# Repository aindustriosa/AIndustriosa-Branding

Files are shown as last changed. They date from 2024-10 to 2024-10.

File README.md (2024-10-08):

# AIndustriosa-Branding
Panel de logos de patrocinadores e colaboradores interactivo, construidos mediante ferramentas de fabricación dixital (Impresión 3D, corte laser, CNC…)

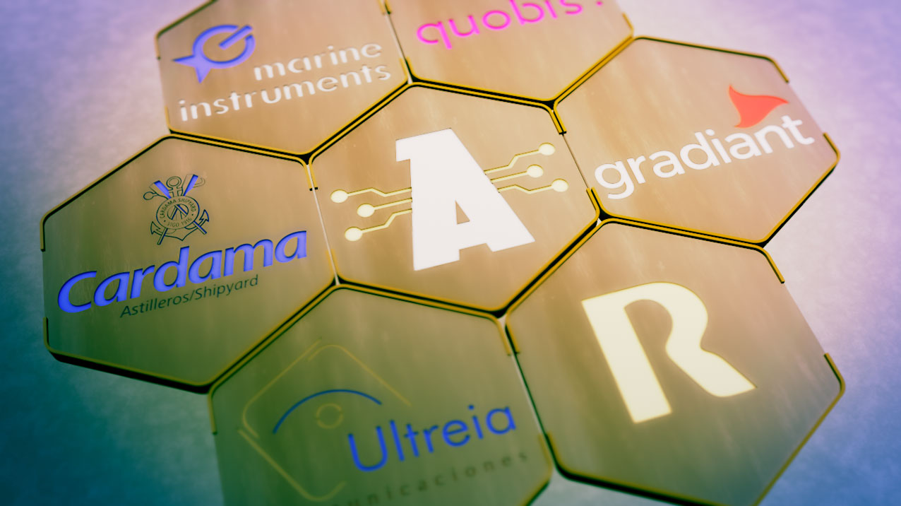
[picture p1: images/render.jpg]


Durante este ano un dos proxectos propostos foi a elaboración dun novo panel de patrocinadores, intentando empregar todos os medios disponibles na Industriosa.

A idea era facer un panel interactivo de logos que se poidese integrar co Home Assistant do local, e usalo tamben de sinalítica.

A parte electrónica usamos tiras de led RGB de 5V coa idea que mediante sinxelas circuitos con un microcontrolador controlar cada panel.

Para empezar o deseño da base foi elaborada con InkScape.

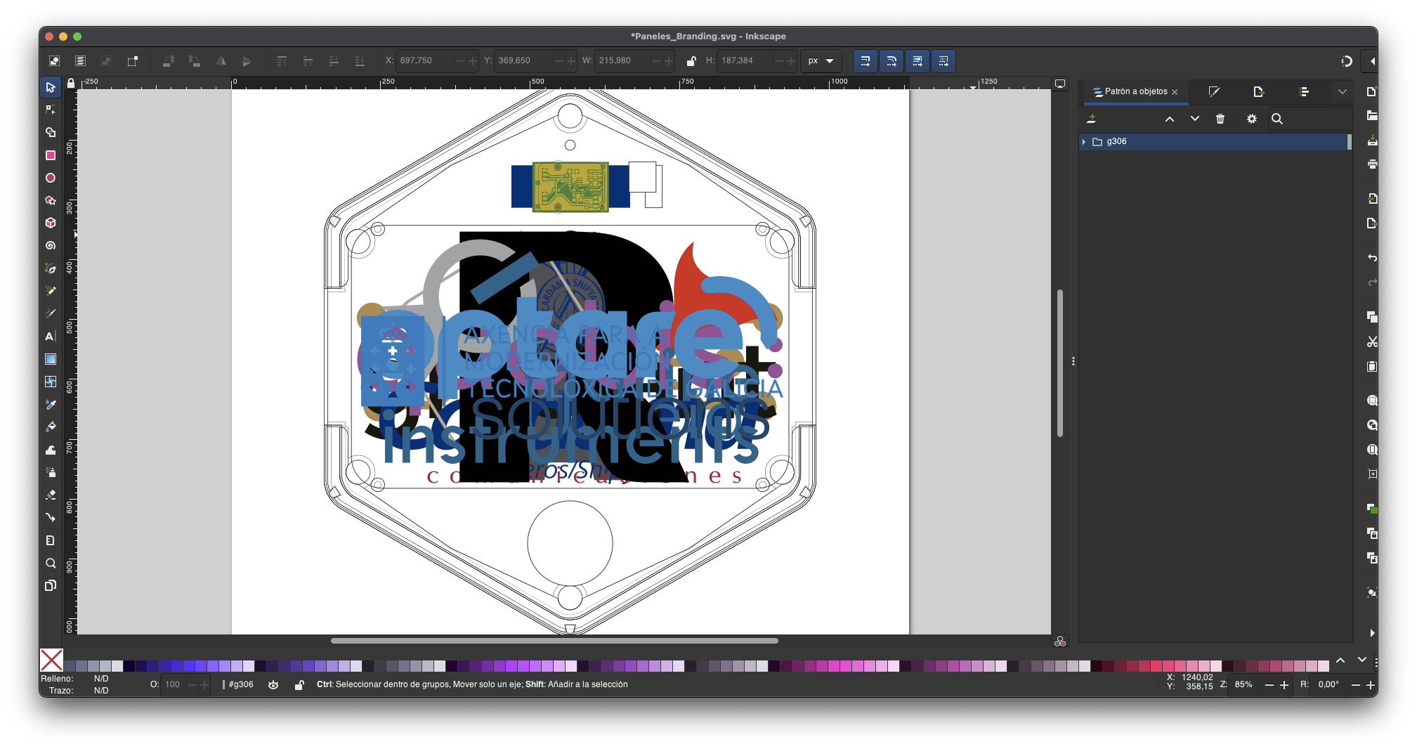
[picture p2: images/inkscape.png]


Partindo los vectores modelamos nun programa de 3d mediante ferramentas de extrusión e operacións boleanas as bases e soportes los leds.

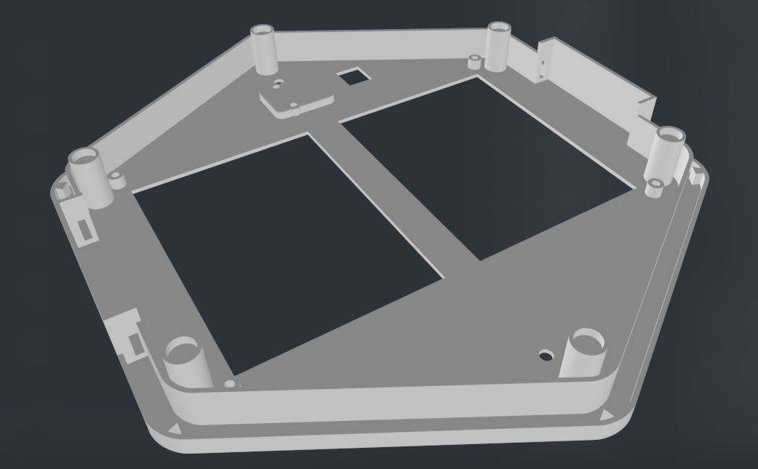
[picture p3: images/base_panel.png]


Con mesmo SVG sacamos os soportes dos leds de cada logo, deixando unha marxe para colocar as luces.

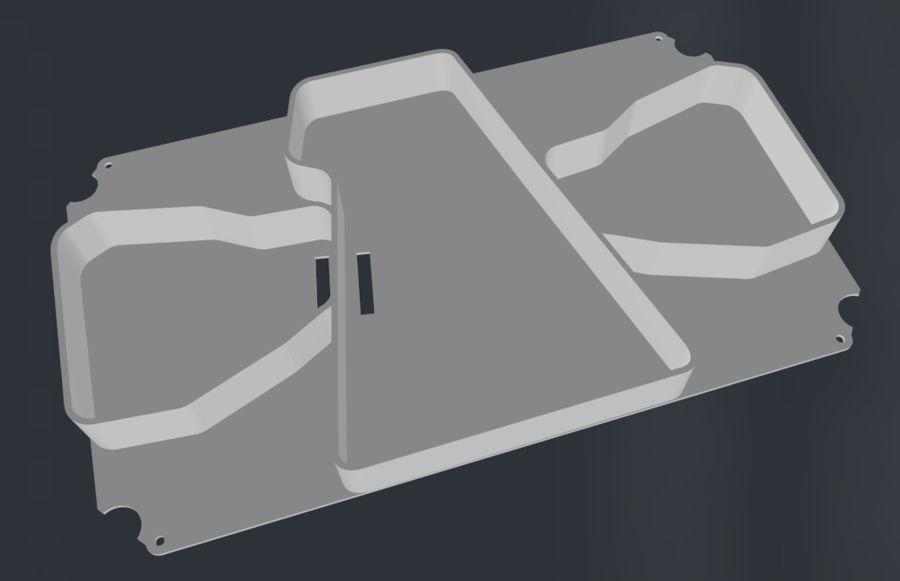
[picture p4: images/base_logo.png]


A maioria dos elementos foron impresos en 3d, dende as bases con PLA negro e as partes translucidas en PLA blanco con apenas 2 capas de recheo.

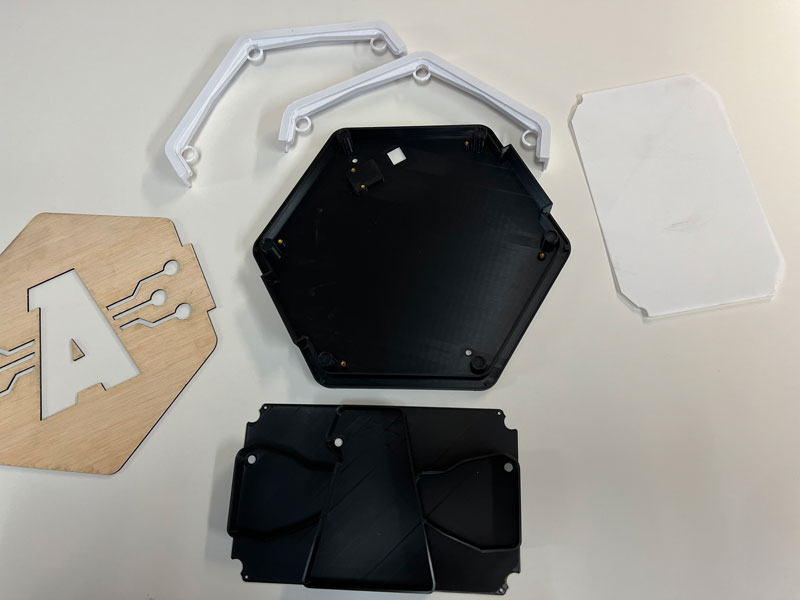
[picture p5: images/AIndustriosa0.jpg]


Para o deseño das pcbs, usamos o kicad, facendo unha sinxela placa cun Atiny412, dos saidas para duas tiras leds, toma de corrente e I2C, así como pin para programalos por UPDI

# Lista de materiais BOM

- Placas de Circuito de PCB **FR1** [Amazon](https://www.amazon.es/dp/B087M1GDCP?psc=1&smid=A839N7HCQOMKL&ref_=chk_typ_imgToDp)
- Fresa 0.4 End Mill -> 1/32 -> 0,4 MM -> TRACES [Aliexpress](https://es.aliexpress.com/item/32914096470.html?spm=a2g0o.order_list.0.0.19bb194dGODsyC&gatewayAdapt=glo2esp)
- Fresa 0.8 End Mill -> 1/64 -> 0,8 MM -> CUT [Aliexpress](https://es.aliexpress.com/item/32914096470.html?spm=a2g0o.order_list.0.0.19bb194dGODsyC&gatewayAdapt=glo2esp)

| Compoñente | Unidades | Código | Tenda | Footprint |
| ----- | ---- | ---- | ---- | ---- |
| ATtiny412 | 1 | ATTINY412-SSF-ND | [Digikey](https://www.digikey.es/en/products/detail/microchip-technology/ATTINY412-SSF/9947539) | SOIC-8_3.9x4.9mm_P1.27mm |
| Cap 10 uF | 1 | GRT31CC8YA106ME01L | [Digikey](https://www.digikey.es/en/products/detail/murata-electronics/GRT31CC8YA106ME01L/5416847) | C_1206 |
| Res 0 Ohms | 1 | RC1206FR-070RL | [Digikey](https://www.digikey.com/en/products/detail/yageo/RC1206FR-070RL/5698945) | R_1206 |
| Res 499 Ohms | 1 | RC1206FR-07499RL | [Digikey](https://www.digikey.es/en/products/detail/yageo/RC1206FR-07499RL/728944) | R_1206 |
| LED RED | 1 | 1516-1076-1-ND  | [Digikey](https://www.digikey.es/es/products/detail/qt-brightek-qtb/QBLP615-R/4814674) | LED_1206 |
| Connector 1x03_P2.54mm_Horizontal | 3 | S1143E-36-ND  | [Digikey](https://www.digikey.es/es/products/detail/sullins-connector-solutions/GBC36SGSN-M89/862355) | PinHeader_1x03_P2.54mm_Horizontal_SMD |
| Connector 2x10_P2.54mm_Vertical | 3 | 20021121-00010T1LF  | [Digikey](https://www.digikey.es/en/products/detail/amphenol-icc-fci/20021121-00010T1LF/4243614) | PinHeader_1x03_P2.54mm_Horizontal_SMD |

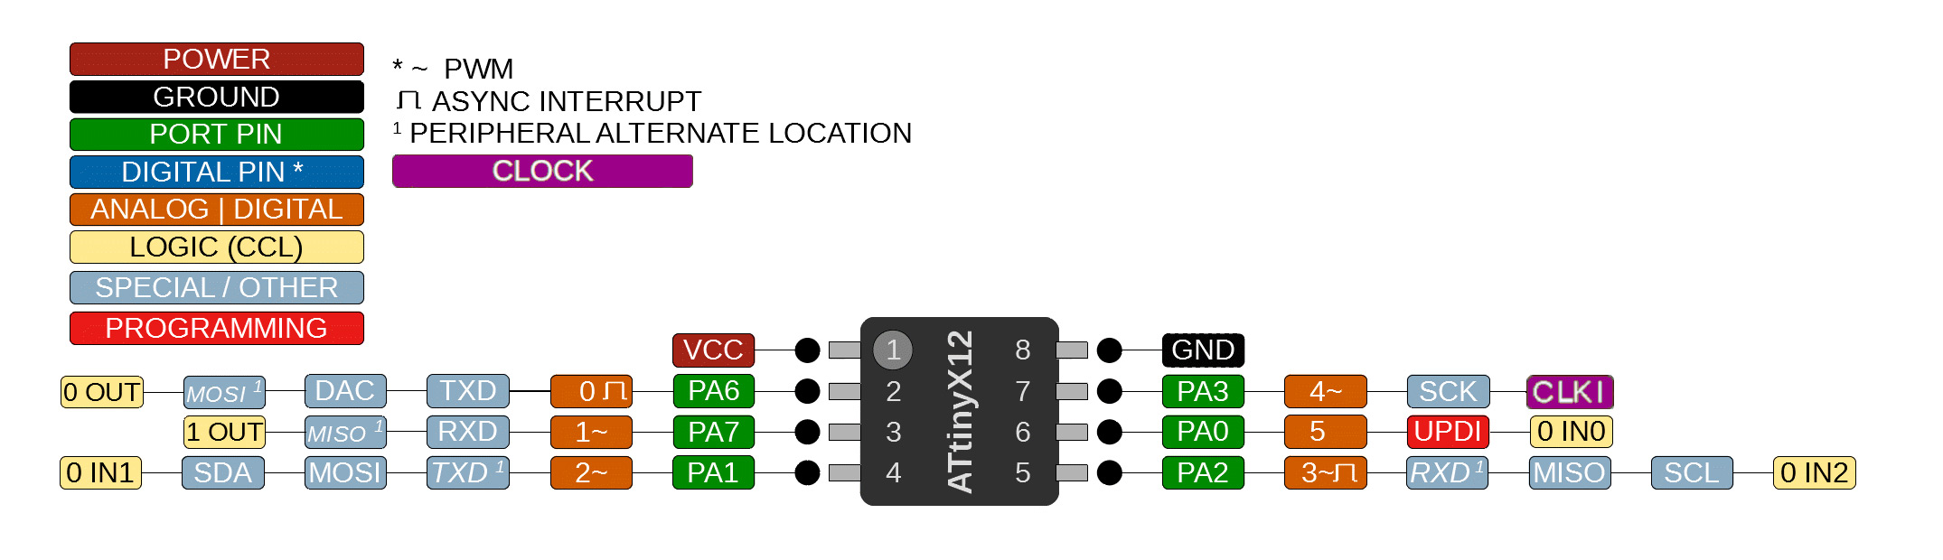
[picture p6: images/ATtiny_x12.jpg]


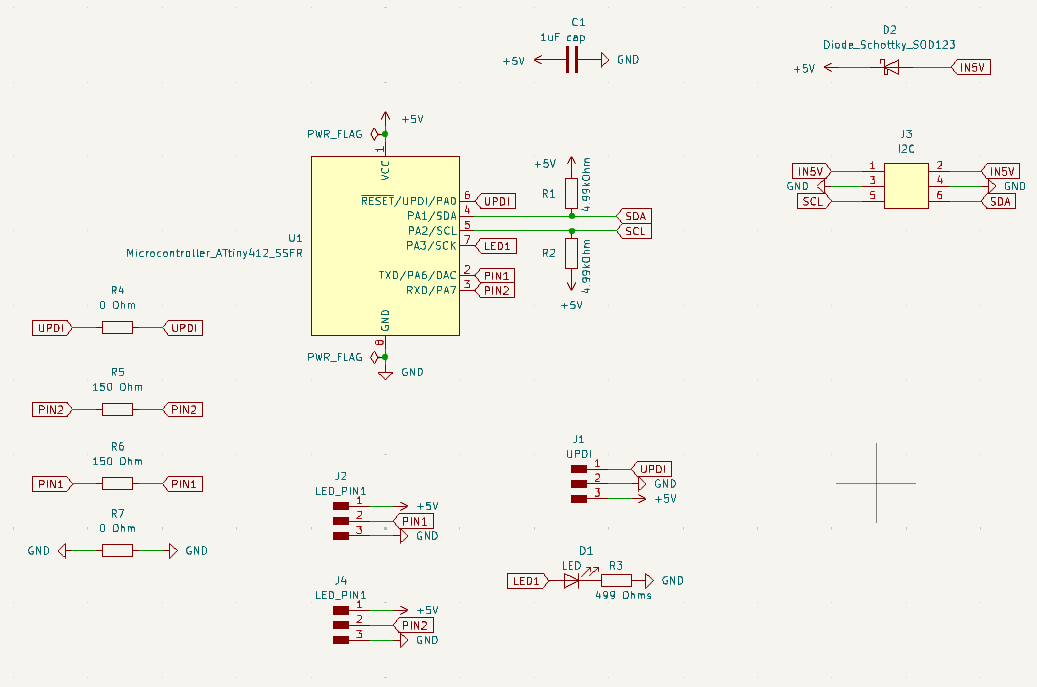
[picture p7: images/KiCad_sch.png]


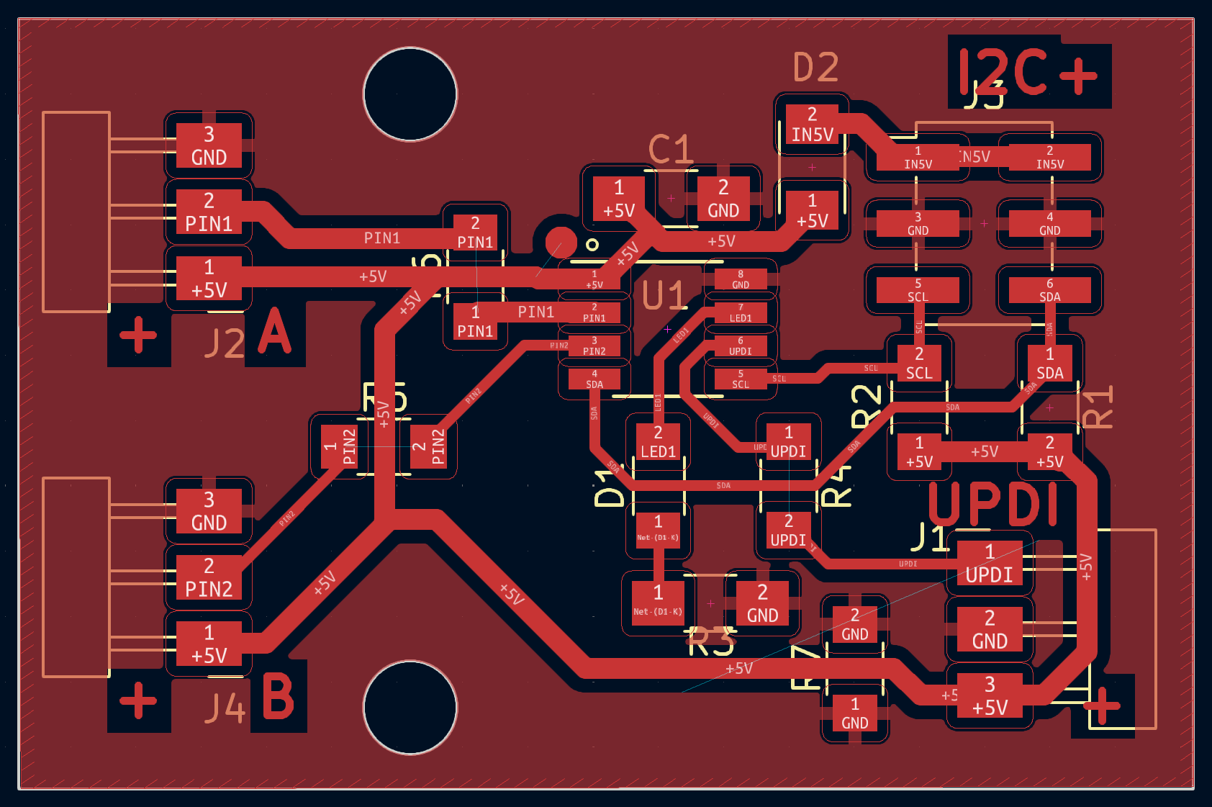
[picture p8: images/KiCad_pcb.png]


Unha vez tiñamos o deseño da PCB exportamos a SVG a capa frontal e a capa de corte, para mediante GIMP xerar os png para facer of gcode con <a href="https://modsproject.org" target="_blank">ModsProject</a>.

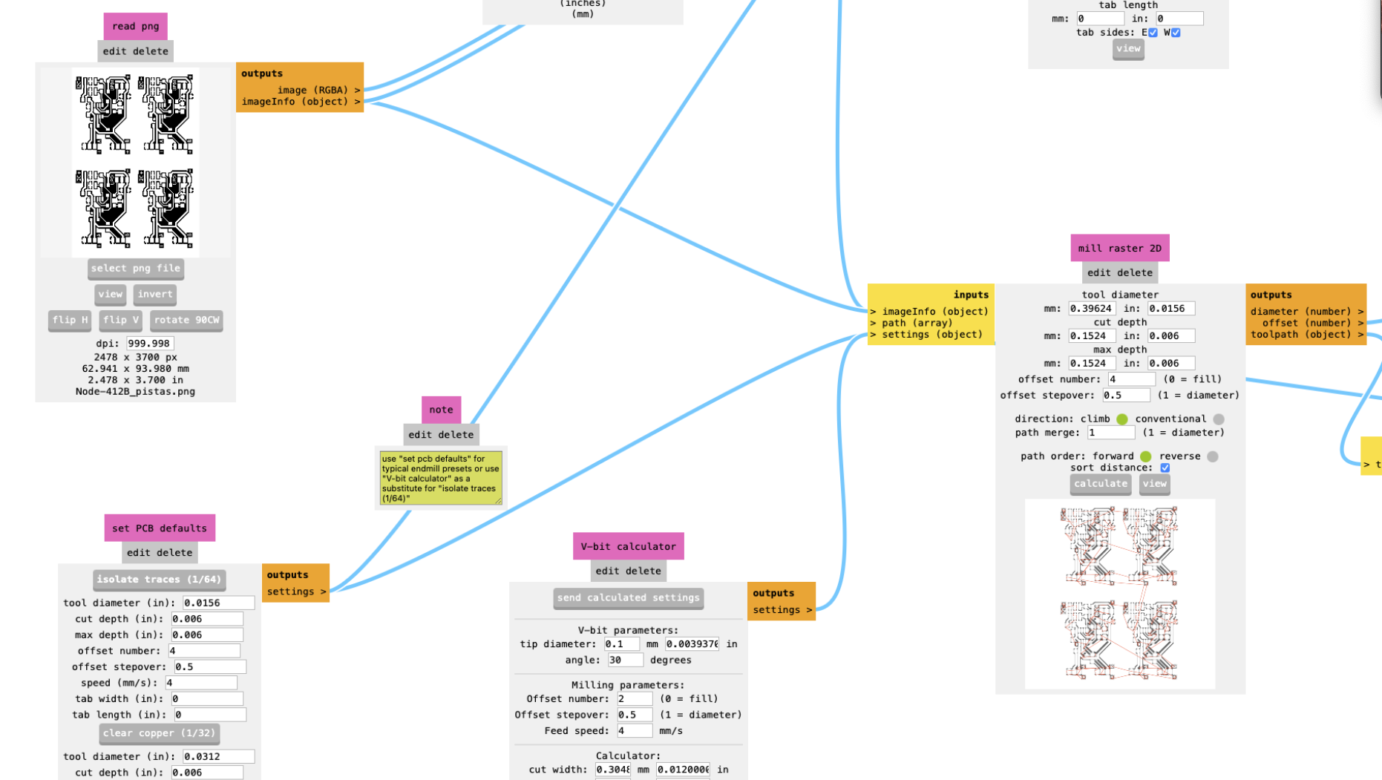
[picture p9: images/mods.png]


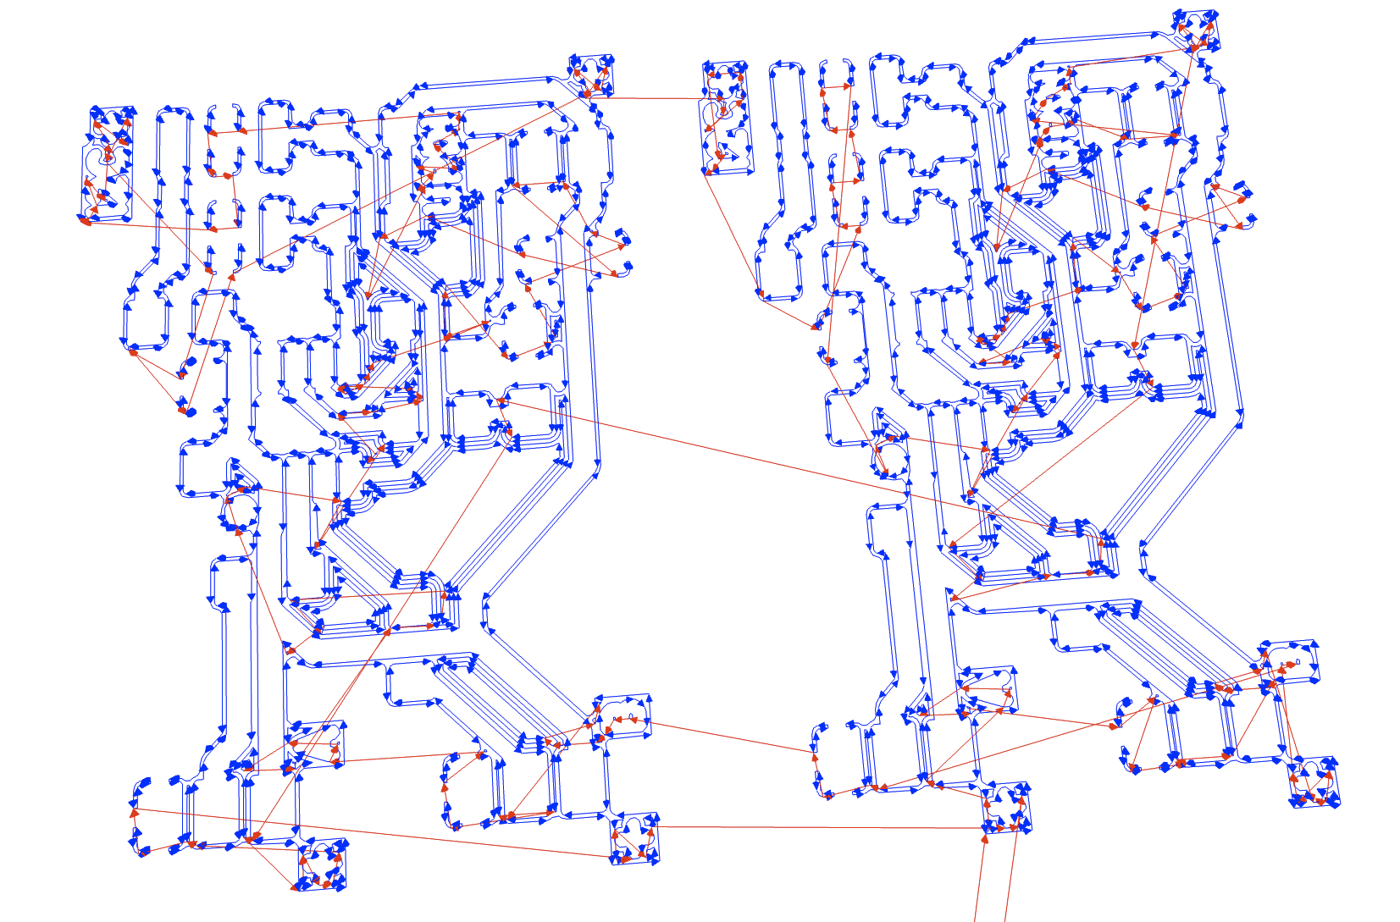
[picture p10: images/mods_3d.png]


Unha vez xerados os gcode, nunha CNC 3018 da asociación, usando o <a href="https://winder.github.io/ugs_website/" target="_blank">UGS</a> fabricamos as placas.

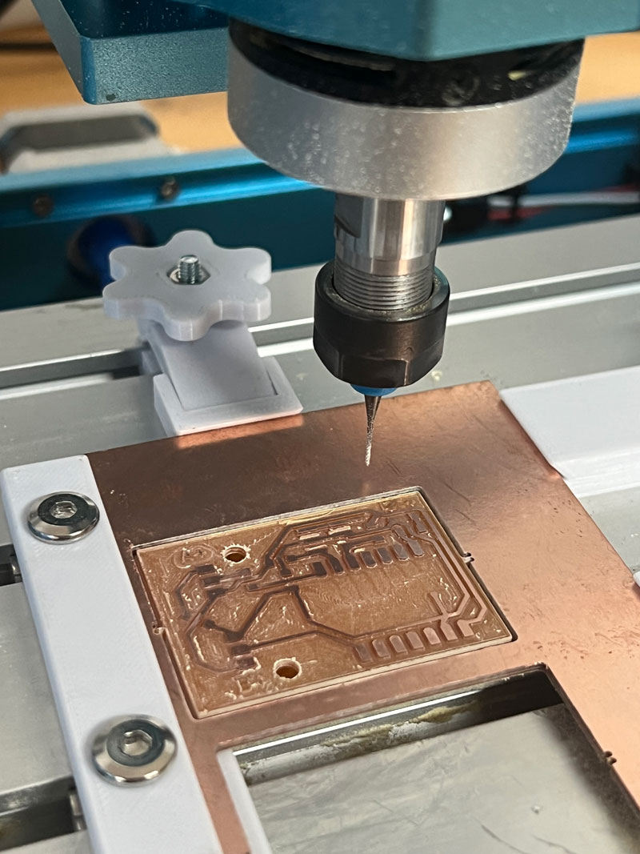
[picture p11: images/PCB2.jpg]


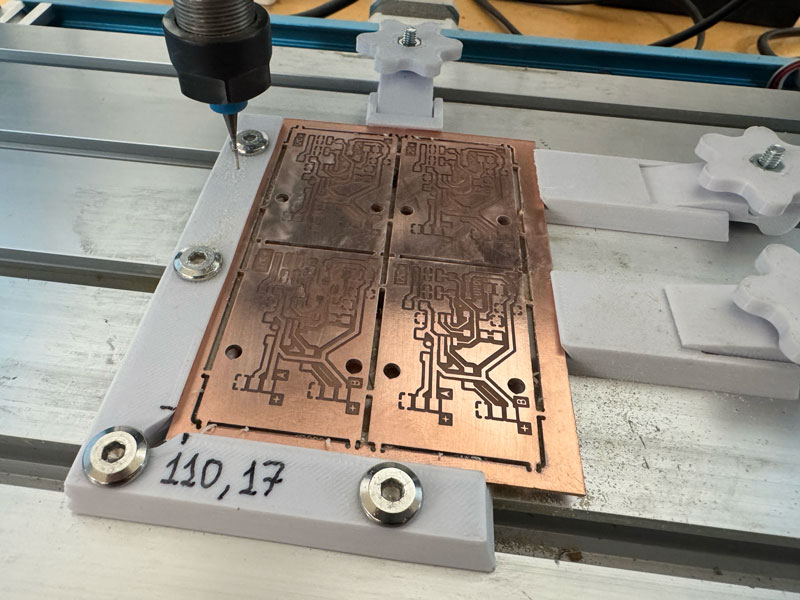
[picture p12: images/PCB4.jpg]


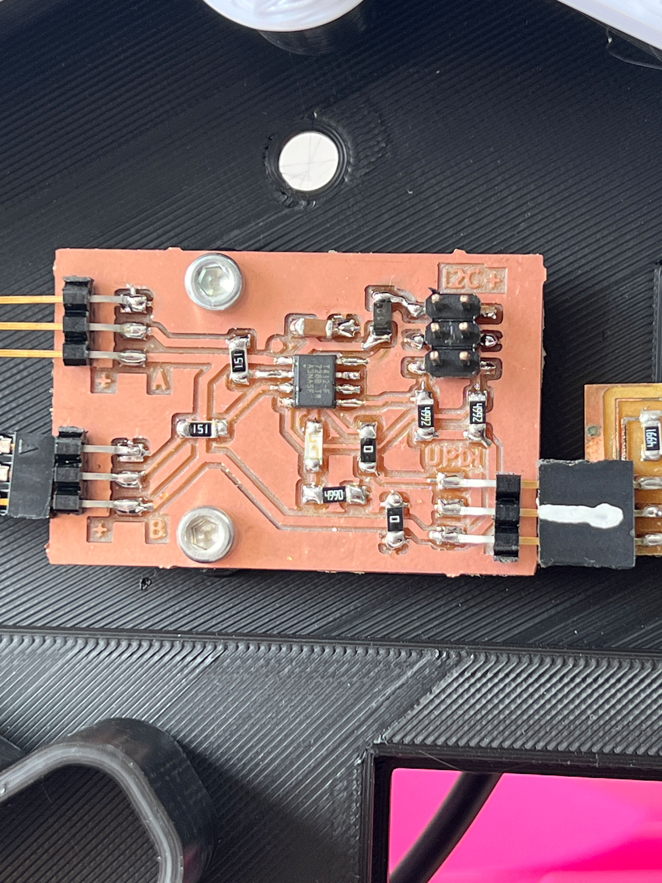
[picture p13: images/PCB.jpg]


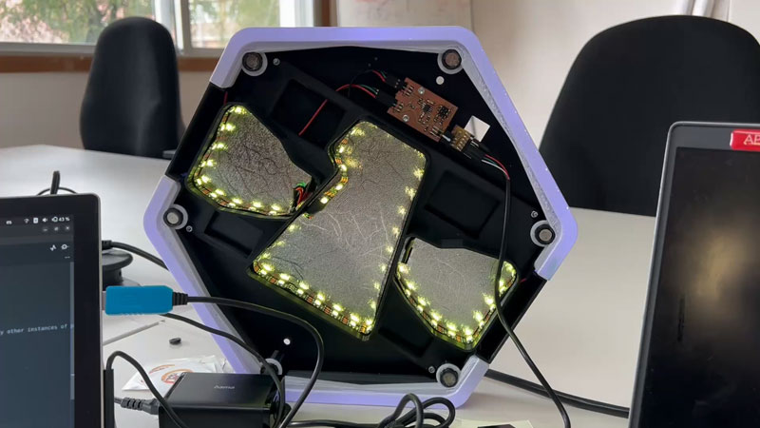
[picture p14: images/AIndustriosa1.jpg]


Unha vez fabricado o primeiro prototipo, mediante Arduino IDE empezamos a programar o funcionamento los LEDs. 

Para programar o Atiny412 a libraría <a href="https://github.com/SpenceKonde/megaTinyCore" target="_blank">megaTinyCore</a>, que inclue control de <a href="https://github.com/SpenceKonde/megaTinyCore/blob/master/megaavr/extras/tinyNeoPixel.md" target="_blank">NeoPixel</a>

Debido o limite de memoria para usar más de 50 led, fixemos no código duas funcións onde despois de encender unha tira dun pin, liberamos a memoria, para encender os outros leds.

Con corte laser cortamos o panel en chopo de 3mm.

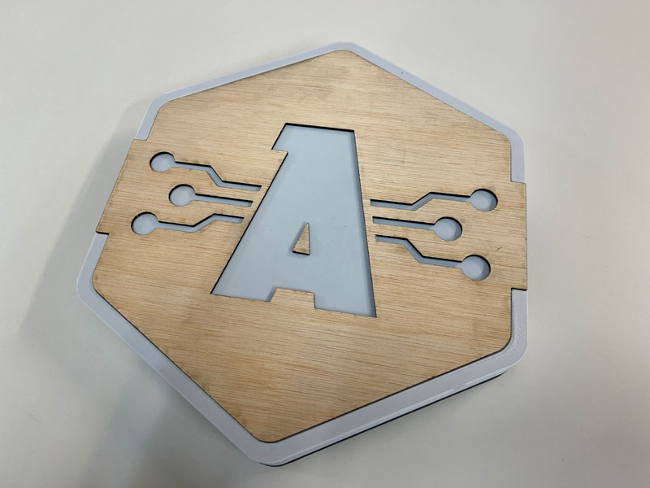
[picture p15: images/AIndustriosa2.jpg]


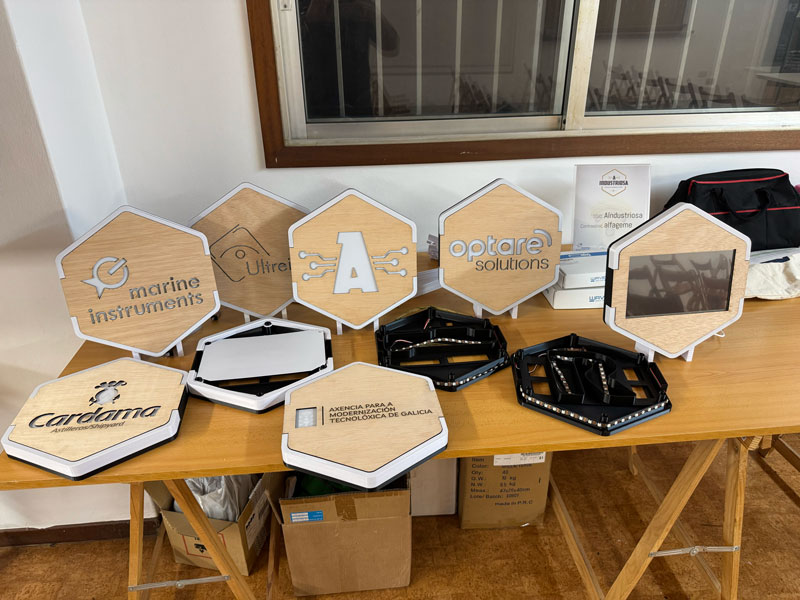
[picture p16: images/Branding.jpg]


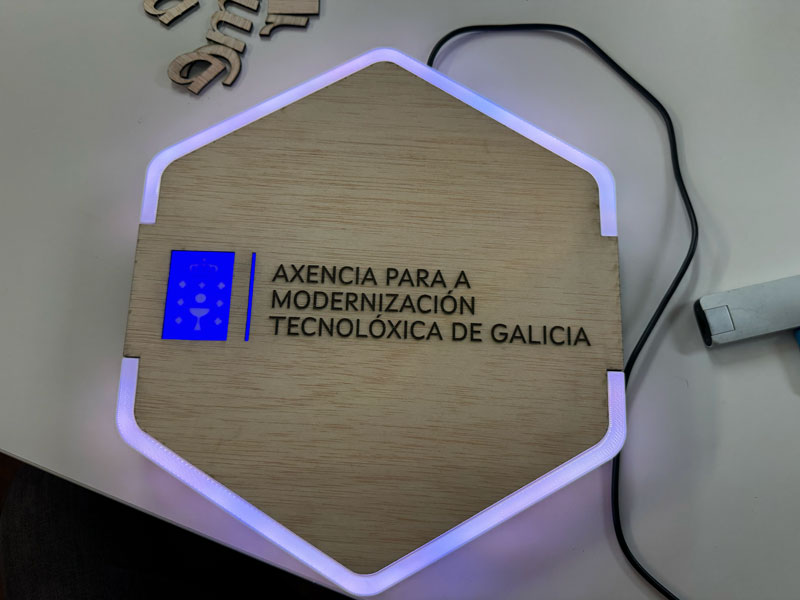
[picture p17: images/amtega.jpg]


<b>Proxecto patrocinado por Xunta de Galicia e Amtega Axencia para a Modernización Tecnolóxica</b>

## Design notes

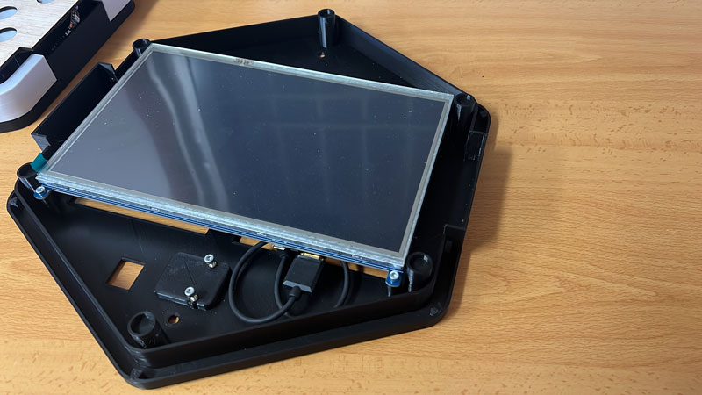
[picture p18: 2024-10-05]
images/PI.jpg

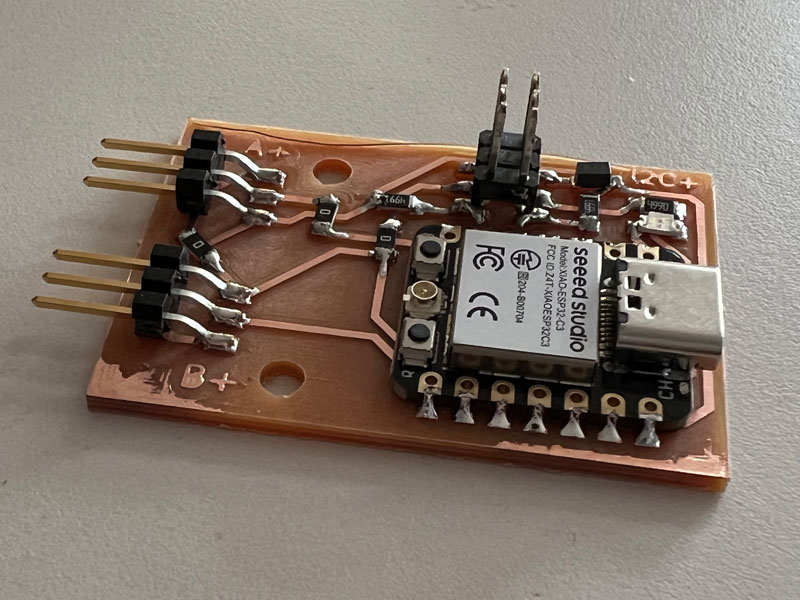
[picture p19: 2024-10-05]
images/PCB3.jpg

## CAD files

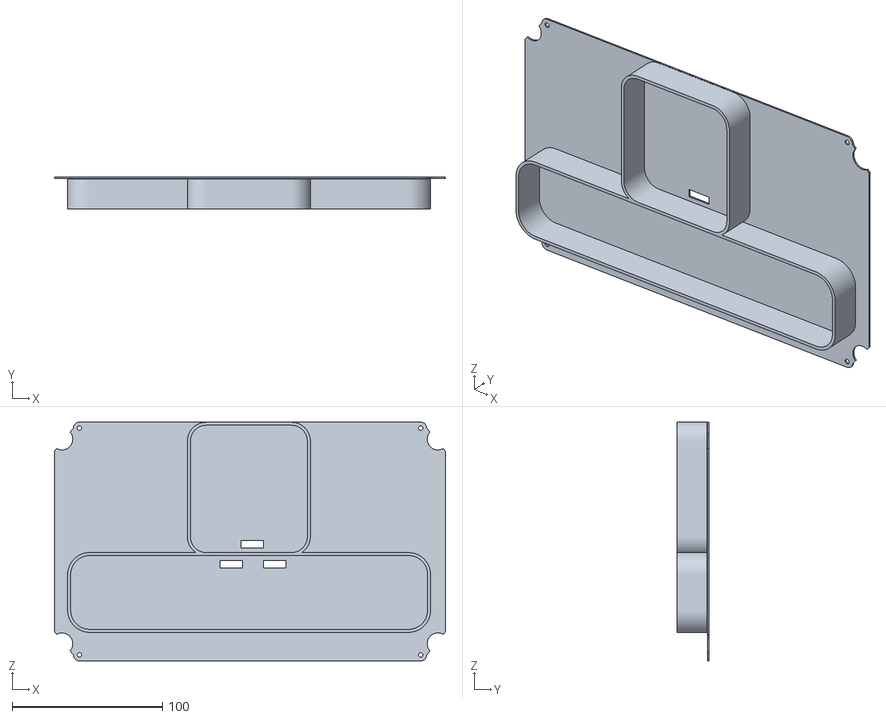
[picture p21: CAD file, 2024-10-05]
1-Impresion3d/3-soporte_Cardama.stl
260.0 x 21.1 x 158.8

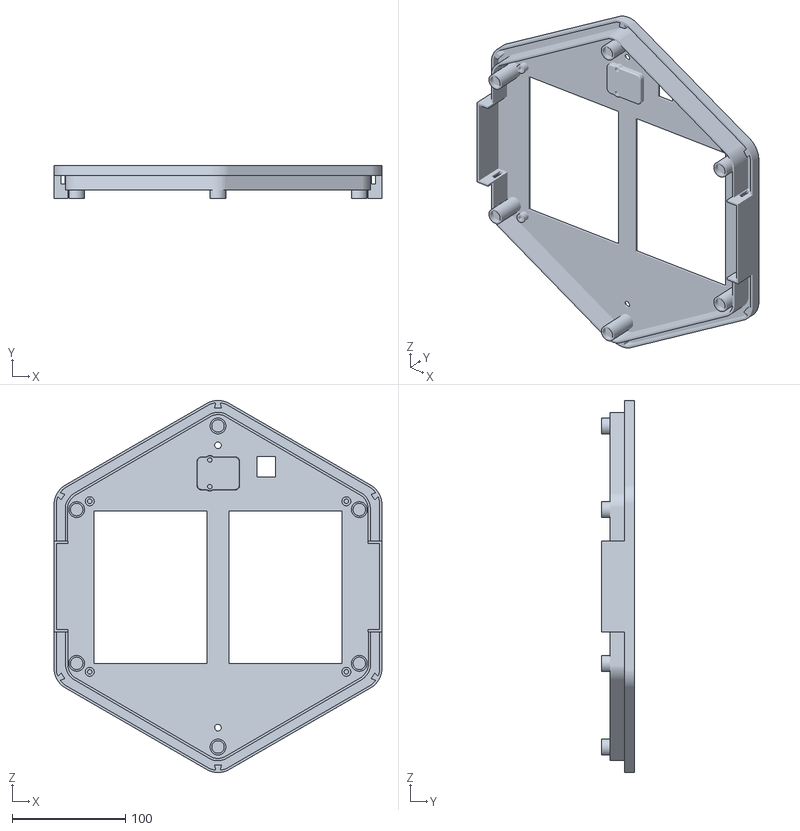
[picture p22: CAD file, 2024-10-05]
1-Impresion3d/base1.stl
290.0 x 29.5 x 329.0

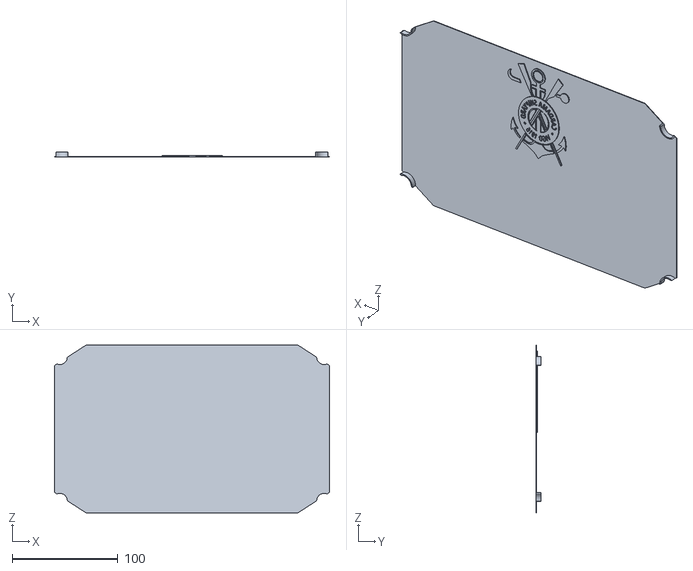
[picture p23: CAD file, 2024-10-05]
1-Impresion3d/Cristal_blanco_Cardama.stl
260.0 x 4.37 x 158.8

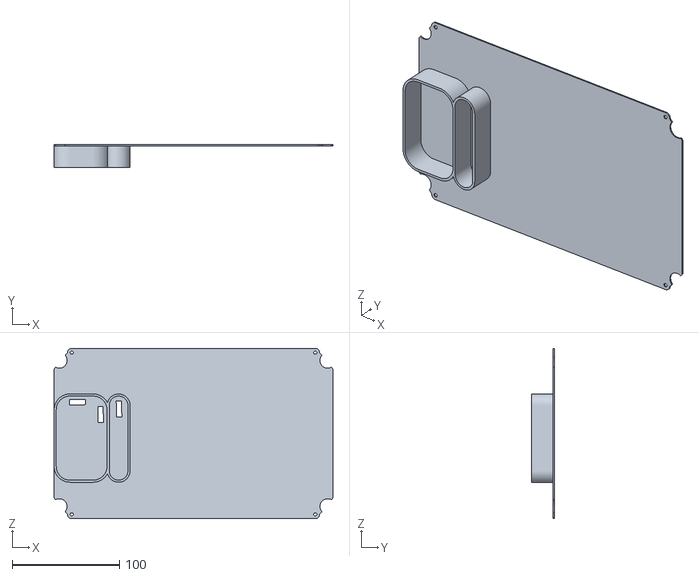
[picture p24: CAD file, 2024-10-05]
1-Impresion3d/9-soporte_Amtega.stl
260.0 x 21.1 x 158.8

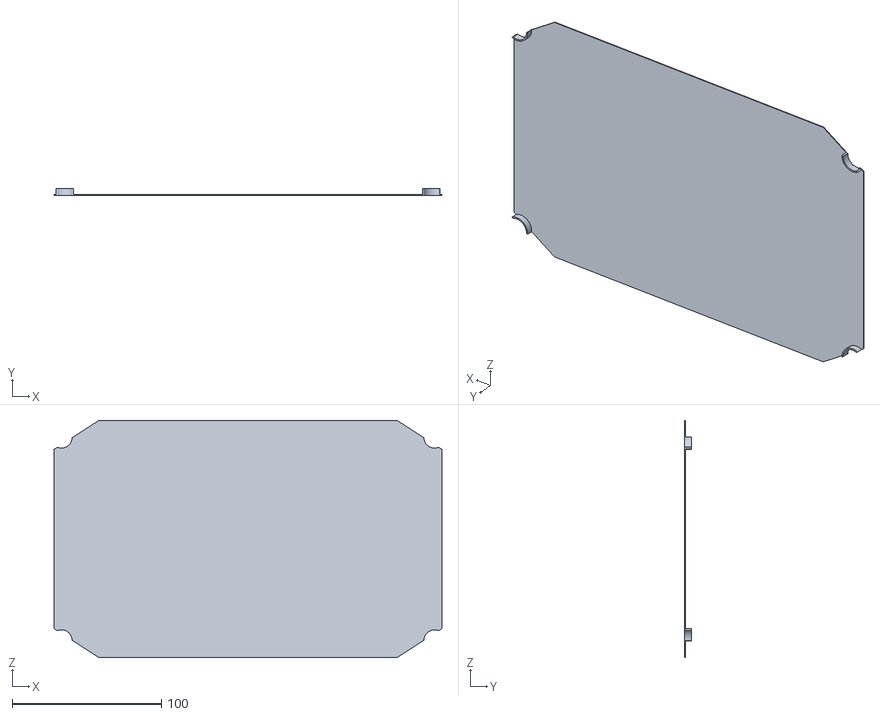
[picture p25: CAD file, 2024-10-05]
1-Impresion3d/Cristal_blanco.stl
260.0 x 4.37 x 158.8

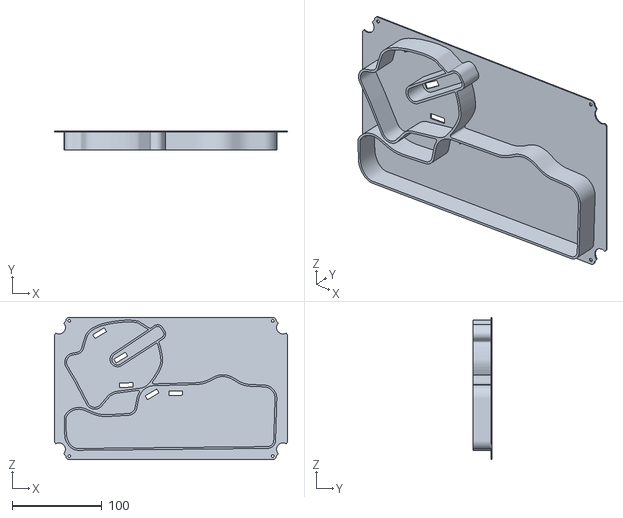
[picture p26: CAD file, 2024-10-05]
1-Impresion3d/7-soporte_Marine_Instruments.stl
260.0 x 21.1 x 158.8

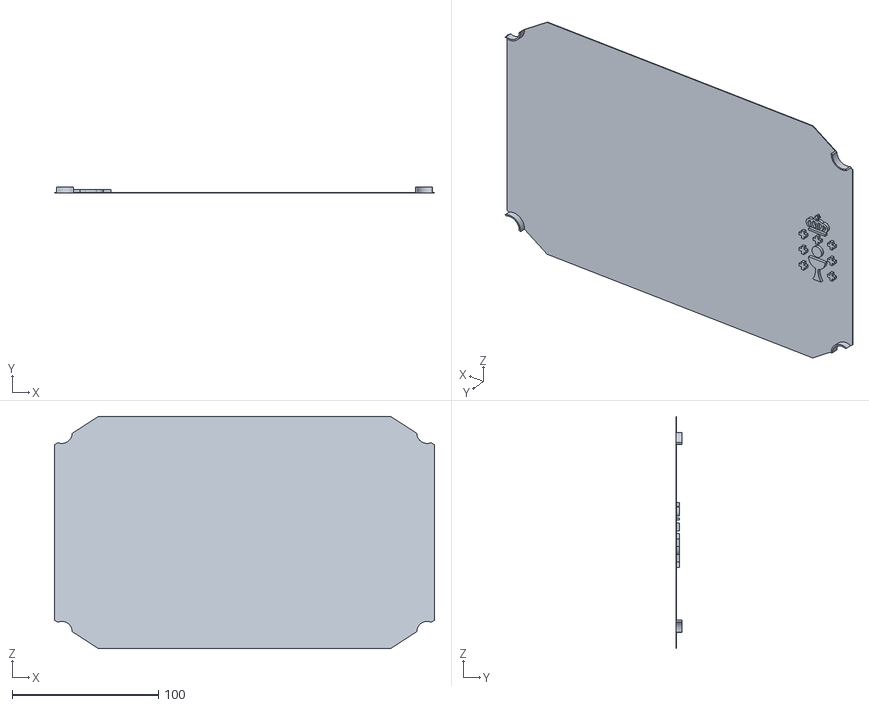
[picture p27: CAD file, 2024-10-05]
1-Impresion3d/Cristal_blanco_AMTEGA.stl
260.0 x 4.37 x 158.8

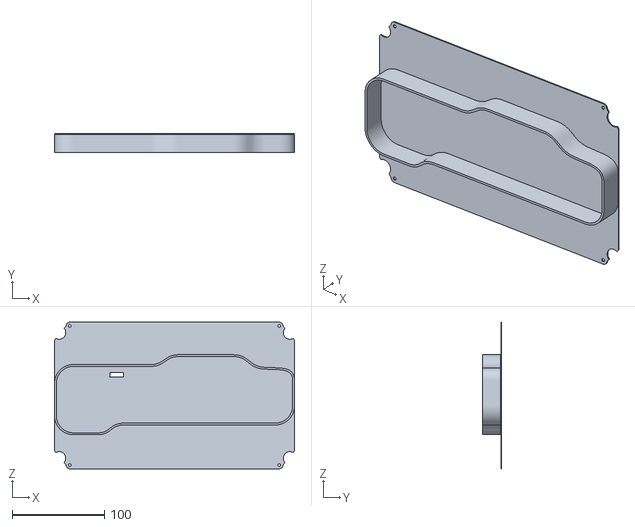
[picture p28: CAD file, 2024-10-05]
1-Impresion3d/6-soporte_Quobis.stl
260.0 x 21.1 x 158.8

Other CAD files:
1-Impresion3d/5-soporte_R.stl
1-Impresion3d/2-soporte_Gradiant.stl
1-Impresion3d/1-soporte_AIndustriosa.stl
1-Impresion3d/8-soporte_Optare.stl
1-Impresion3d/4-soporte_Ultreia.stl

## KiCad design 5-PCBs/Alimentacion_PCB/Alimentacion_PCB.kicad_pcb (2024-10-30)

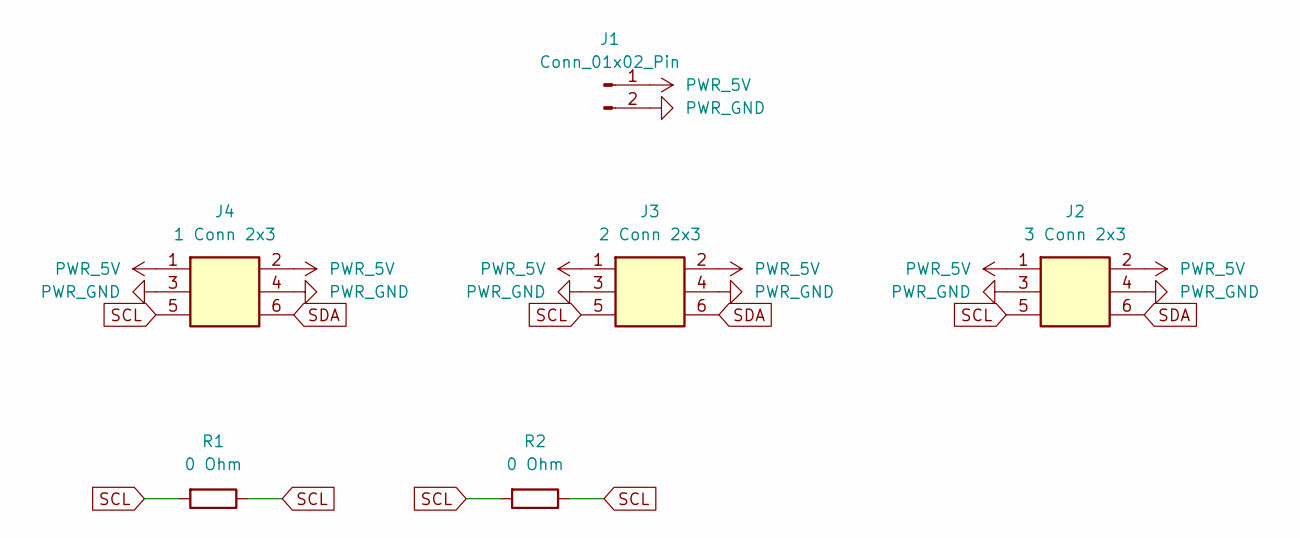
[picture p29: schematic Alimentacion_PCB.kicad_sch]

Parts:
J1: Conn_01x02_Pin; TE_2834006-2_1x02_P4.0mm_Horizontal
J2: 3 Conn 2x3; PinHeader_2x03_P2.54mm_Vertical_SMD
J3: 2 Conn 2x3; PinHeader_2x03_P2.54mm_Vertical_SMD
J4: 1 Conn 2x3; PinHeader_2x03_P2.54mm_Vertical_SMD
R1, R2: 0 Ohm; R_1206

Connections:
PWR_5V: J1.1, J2.1, J2.2, J3.1, J3.2, J4.1, J4.2
PWR_GND: J1.2, J2.3, J2.4, J3.3, J3.4, J4.3, J4.4
SCL: J2.5, J3.5, J4.5, R1.1, R1.2, R2.1, R2.2
SDA: J2.6, J3.6, J4.6

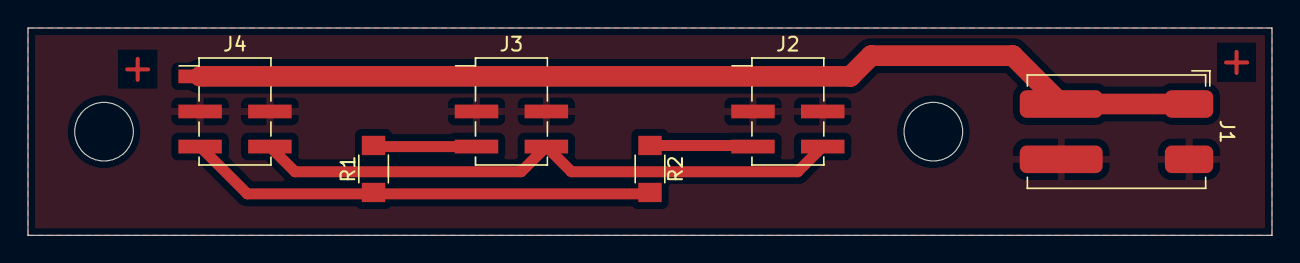
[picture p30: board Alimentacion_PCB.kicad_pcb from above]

Board: 2 copper layers, 90.0 x 15.0 mm, 6 parts (0 on the bottom side), 4 nets.

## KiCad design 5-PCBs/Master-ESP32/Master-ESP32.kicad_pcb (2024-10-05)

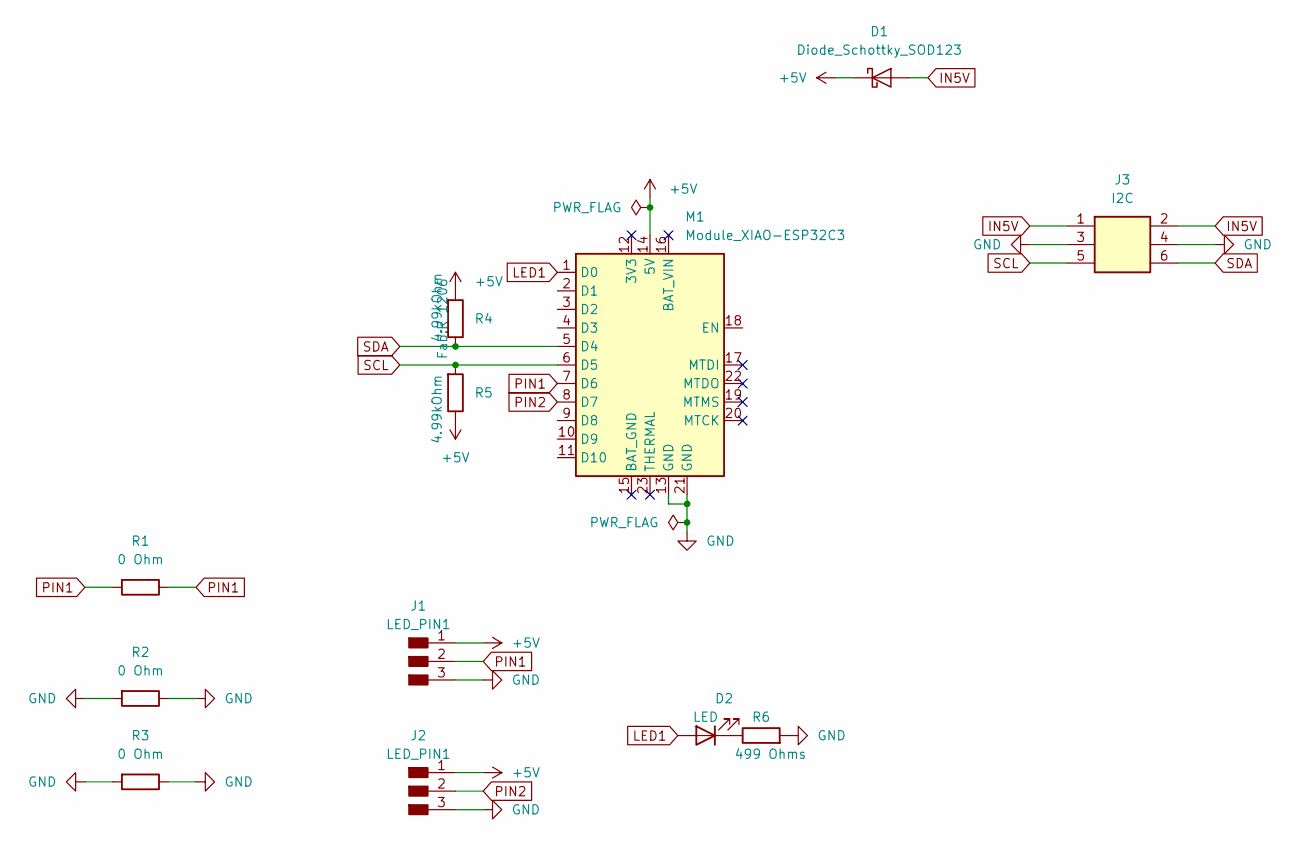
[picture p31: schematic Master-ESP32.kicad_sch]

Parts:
D1: Diode_Schottky_SOD123; SOD-123
D2: LED; LED_1206
J1, J2: LED_PIN1; PinHeader_1x03_P2.54mm_Horizontal_SMD
J3: I2C; PinHeader_2x03_P2.54mm_Vertical_SMD
M1: Module_XIAO-ESP32C3; SeeedStudio_XIAO_ESP32C3
R1, R2, R3: 0 Ohm; R_1206
R4, R5: 4.99kOhm; R_1206
R6: 499 Ohms; R_1206

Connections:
+5V: D1.1 (K), J1.1, J2.1, M1.14 (5V), R4.2, R5.1
GND: J1.3, J2.3, J3.3, J3.4, M1.13 (GND), M1.21 (GND), R2.1, R2.2, R3.1, R3.2, R6.2
IN5V: D1.2 (A), J3.1, J3.2
LED1: D2.2 (A), M1.1 (D0)
unnamed: D2.1 (K), R6.1
PIN1: J1.2, M1.7 (D6), R1.1, R1.2
PIN2: J2.2, M1.8 (D7)
SCL: J3.5, M1.6 (D5), R5.2
SDA: J3.6, M1.5 (D4), R4.1

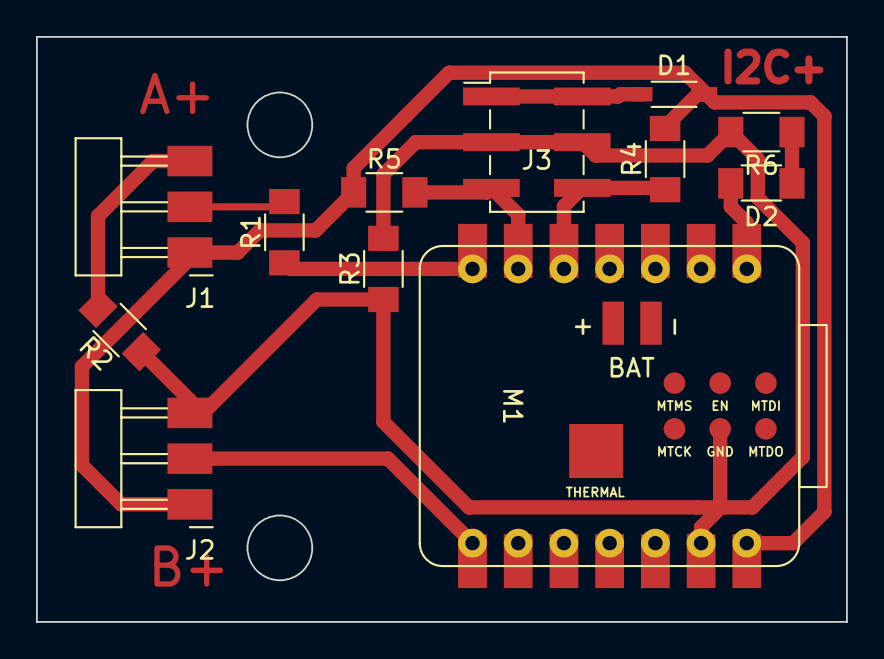
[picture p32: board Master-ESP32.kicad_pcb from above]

Board: 2 copper layers, 45.0 x 32.5 mm, 12 parts (0 on the bottom side), 9 nets.

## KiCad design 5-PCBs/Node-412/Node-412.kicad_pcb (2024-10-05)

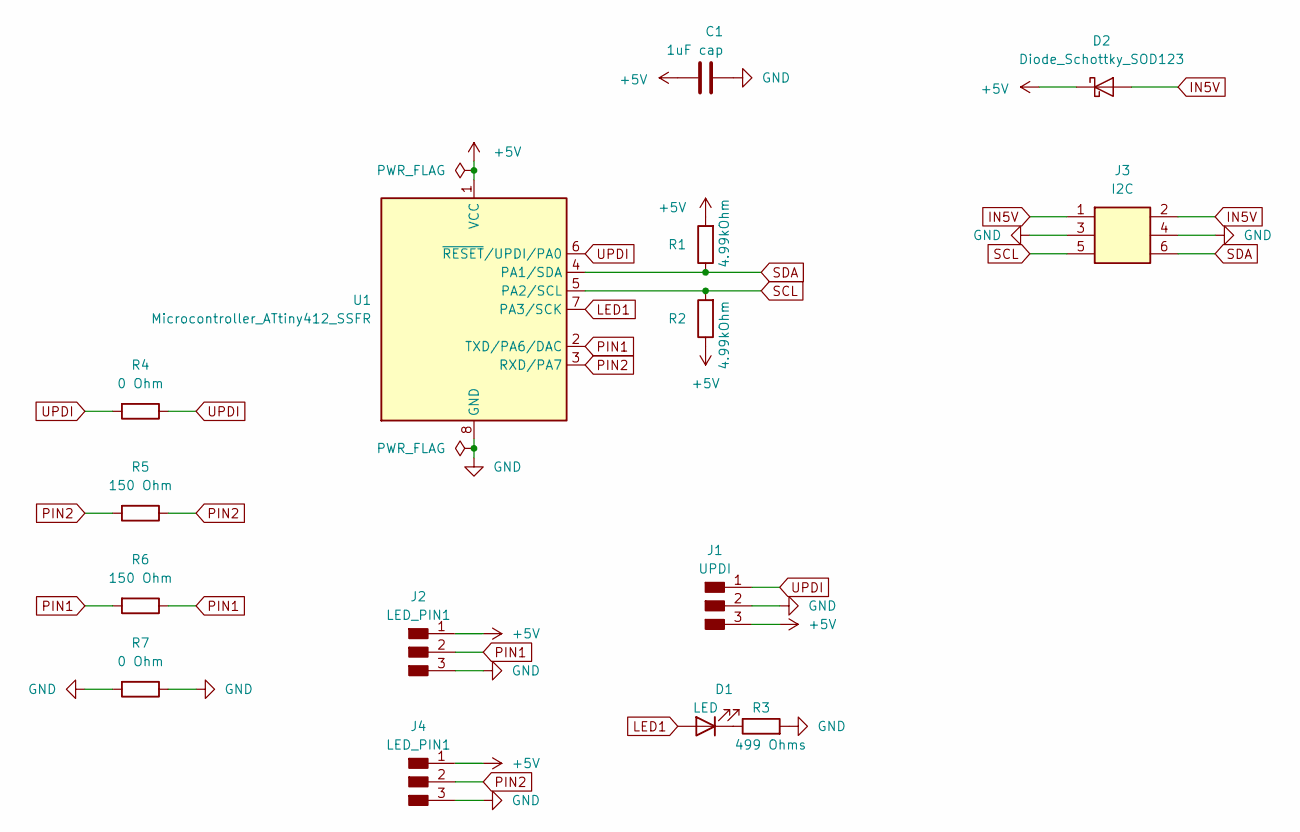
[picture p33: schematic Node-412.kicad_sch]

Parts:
C1: 1uF cap; C_1206
D1: LED; LED_1206
D2: Diode_Schottky_SOD123; SOD-123T
J1: UPDI; PinHeader_1x03_P2.54mm_Horizontal_SMD
J2, J4: LED_PIN1; PinHeader_1x03_P2.54mm_Horizontal_SMD
J3: I2C; PinHeader_2x03_P2.54mm_Vertical_SMD
R1, R2: 4.99kOhm; R_1206
R3: 499 Ohms; R_1206
R4, R7: 0 Ohm; R_1206
R5, R6: 150 Ohm; R_1206
U1: Microcontroller_ATtiny412_SSFR; SOIC-8_3.9x4.9mm_P1.27mm

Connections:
+5V: C1.1, D2.1 (K), J1.3, J2.1, J4.1, R1.2, R2.1, U1.1 (VCC)
GND: C1.2, J1.2, J2.3, J3.3, J3.4, J4.3, R3.2, R7.1, R7.2, U1.8 (GND)
IN5V: D2.2 (A), J3.1, J3.2
LED1: D1.2 (A), U1.7 (PA3/SCK)
unnamed: D1.1 (K), R3.1
PIN1: J2.2, R6.1, R6.2, U1.2 (TXD/PA6/DAC)
PIN2: J4.2, R5.1, R5.2, U1.3 (RXD/PA7)
SCL: J3.5, R2.2, U1.5 (PA2/SCL)
SDA: J3.6, R1.1, U1.4 (PA1/SDA)
UPDI: J1.1, R4.1, R4.2, U1.6 (~RESET/UPDI/PA0)

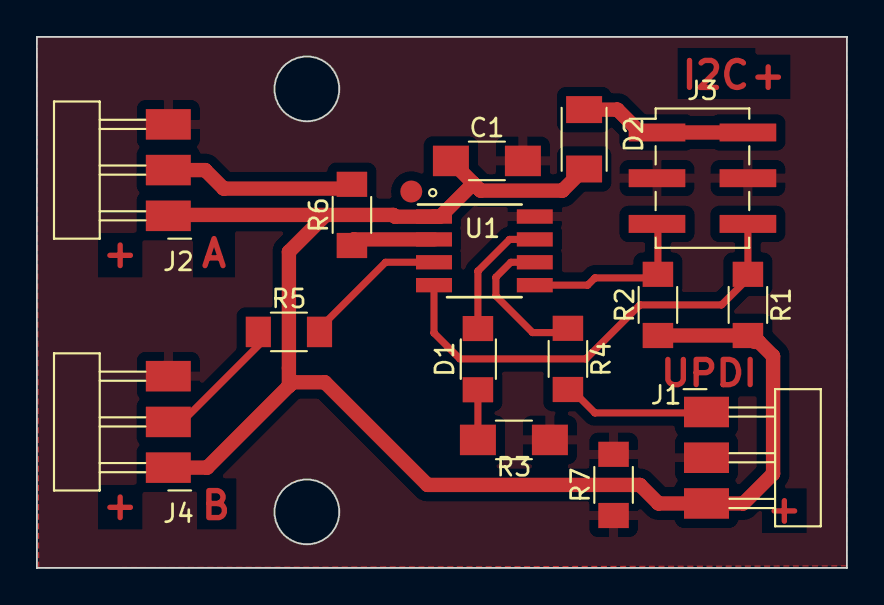
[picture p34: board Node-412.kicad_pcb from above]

Board: 2 copper layers, 45.0 x 29.5 mm, 15 parts (0 on the bottom side), 10 nets.

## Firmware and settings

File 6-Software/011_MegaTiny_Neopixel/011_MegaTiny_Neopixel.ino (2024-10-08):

// PANEL 1 - A Industriosa

#include <tinyNeoPixel.h>

// #define NUMLEDS6 1 // 7  // logotipo A Industriosa
#define NUMLEDS7 27 // 4  // Bordes logos


// tinyNeoPixel leds6 = tinyNeoPixel(NUMLEDS6, PIN_PA6, NEO_GRB );
tinyNeoPixel leds7 = tinyNeoPixel(NUMLEDS7, PIN_PA7, NEO_GRB);

void setup() {

  // leds6.begin();
  leds7.begin();

  // leds6.clear();  // LED turns off.
  leds7.clear();  // LED turns off.

  delay(1000);
}
void loop() { /* empty loop */

  // leds6.begin();
  leds7.begin();

  /* for (int i = 0; i < NUMLEDS6; i++) {  // Logo Arduino
    leds6.setPixelColor(i, 150, 123, 5);
  }*/

  for (int i = 0; i < NUMLEDS7; i++) {  // borde
    leds7.setPixelColor(i, 0, 0, 250);
  }

  // leds6.show();
  leds7.show();  // LED turns on.

  delay(1000);

  // leds6.clear();
  leds7.clear();  // LED turns on.
  leds7.show();  // LED turns on.

  delay(1000);
}

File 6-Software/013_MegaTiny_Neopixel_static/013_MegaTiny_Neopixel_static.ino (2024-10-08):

#include <tinyNeoPixel_Static.h>
#define NUMLEDS 44
byte pixels[NUMLEDS * 3];
#define NUMLEDS6 15
byte pixels6[NUMLEDS6 * 3];
tinyNeoPixel leds = tinyNeoPixel(NUMLEDS, PIN_PA7, NEO_GRB, pixels);
tinyNeoPixel leds6 = tinyNeoPixel(NUMLEDS6, PIN_PA6, NEO_GRB, pixels6);
void setup() {
  pinMode(PIN_PA7, OUTPUT);  //pinModeFast() now exists and would shave a few more bytes off if this and any other instances of pinMode were converted to pinModeFast.
  pinMode(PIN_PA6, OUTPUT);

   for (int i = 0; i < NUMLEDS6; i++) {  // borde
    leds6.setPixelColor(i, 50, 50, 0);
  }
 leds6.show();  // LED turns on.

}
void loop() { /* empty loop */

  for (int i = 0; i < NUMLEDS; i++) {  // borde
    leds.setPixelColor(i, 50, 50, 50);
  }
 leds.setPixelColor(random(NUMLEDS), 255, 255, 255);
  leds.show();   // LED turns on.

 

  delay(100);
}
